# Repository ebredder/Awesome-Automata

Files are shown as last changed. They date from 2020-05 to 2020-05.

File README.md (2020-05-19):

# Awesome-Automata
Create large group automata for events and group projects to learn basic mechanisms.

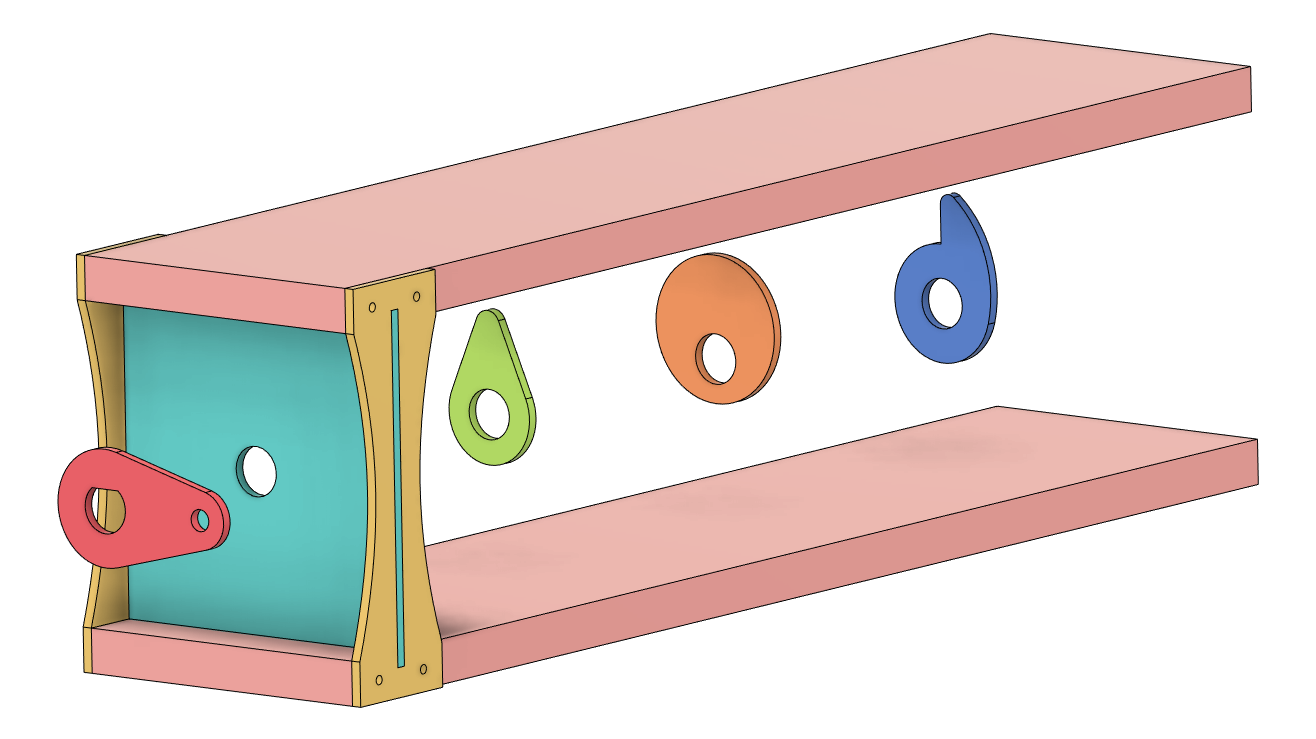
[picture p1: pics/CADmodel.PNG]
CAD


#### Materials Required:  
+ 1/2" ID Black Iron Pipe (length of your choosing)  
+ 6" (5.5" actual) Wide Board  
+ Wood Glue  
+ 5/8" Dowel Rods  
+ 1 1/4" #6 Screws  
+ 3/8" Bolt/Nut

#### Minimum Tools Required:  
+ Hacksaw  
+ Drill/Driver  
+ Screwdriver  
+ Metal File  
+ Sandpaper  
+ Crosscut Saw  
+ Circular Saw/Table Saw  

#### Optional Materials
+ Paint Supplies
+ Hot Glue/CA Glue
+ Foam Board, Craft Supplies, etc...
+ Paste Wax for lubrication

The sides can be made using a laser cutter, CNC Router, or even just printing the 1:1 templates and cutting with a bandsaw or jigsaw works too!

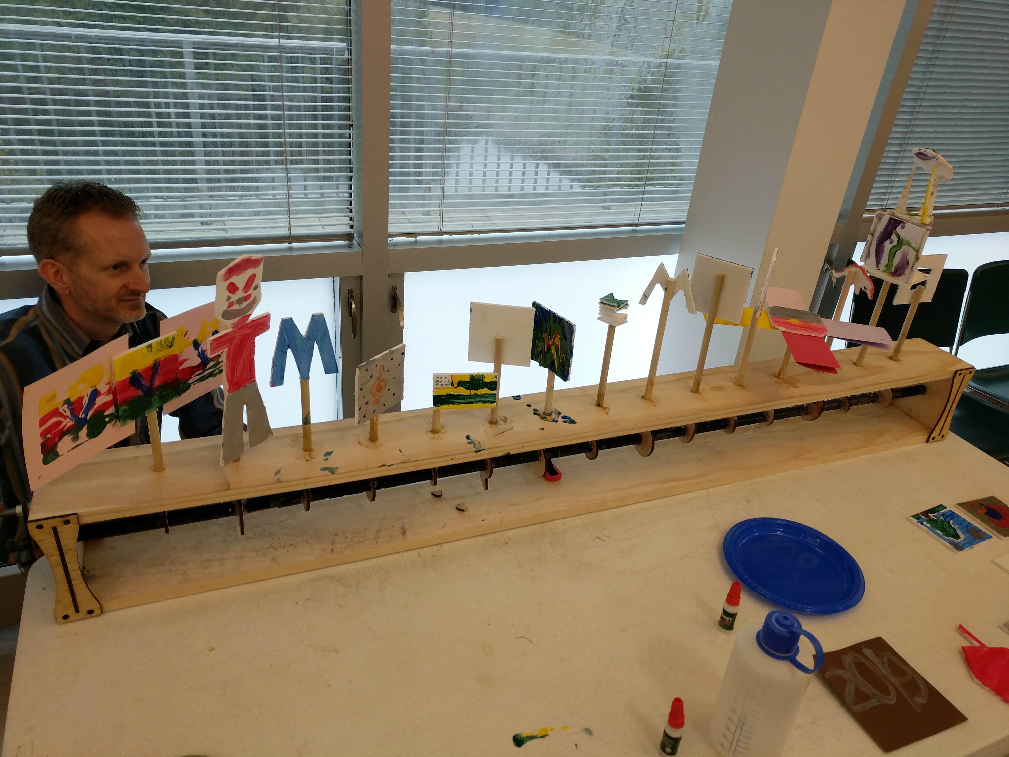
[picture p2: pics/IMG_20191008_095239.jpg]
project


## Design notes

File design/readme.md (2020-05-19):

All basic design files to get started are uploaded here. A Fusion 360 model of the construction of one side is located here (.f3d) with some 2D template exports of the pieces (.dxf) along with a complete project laser cut template (.svg).

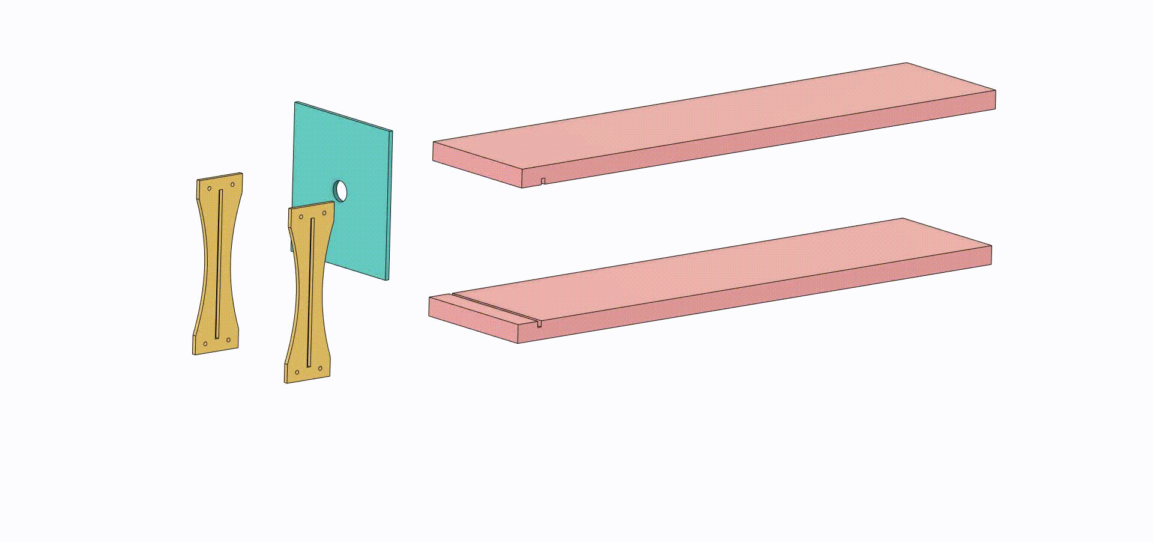
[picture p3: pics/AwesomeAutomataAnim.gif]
anim


#### Design for 5mm thick material - 

3 Cam profiles: Eccentric, Pear, Snail

4x Side Supports for frame  
2x Center Support for frame

1x Handle for crank mechanism

Center holes from cam used as followers on the cam shafts.

Laser Cut template also below to fit a 12x24" bed. Creates several cam profiles and all the required materials for one scalable mechanism.

**Note 1: Each of the boards will receive a 1/4" deep, 5mm (material thickness) wide dado that is 1" from each end of the board on the top and bottom. This makes 4 dados total.**

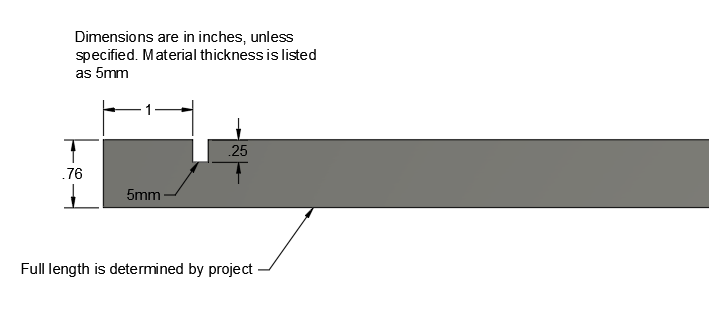
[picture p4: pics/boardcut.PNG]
board Dim
 

**Note 2: The iron pipe must be filed about .1" down to receive the crank in order to properly turn all the cams**

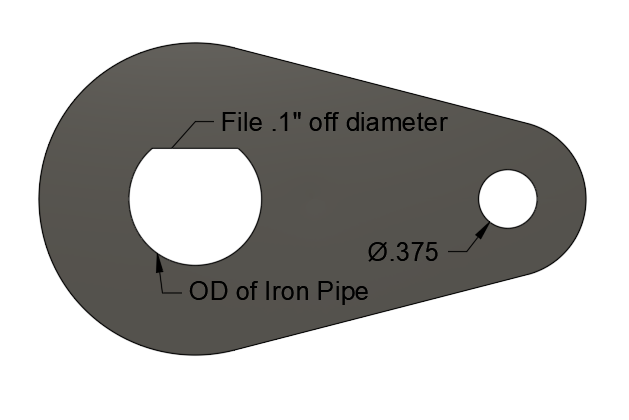
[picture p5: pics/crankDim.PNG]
crank


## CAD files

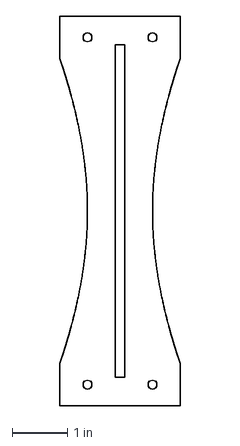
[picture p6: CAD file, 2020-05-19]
design/sideSupport.dxf
2.17 x 7.02 in

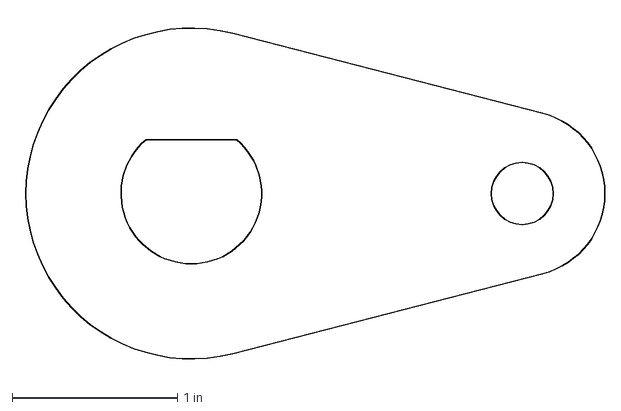
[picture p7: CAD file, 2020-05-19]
design/handle.dxf
3.56 x 2.15 in

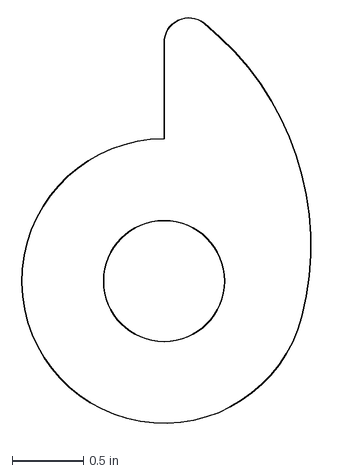
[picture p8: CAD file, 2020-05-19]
design/snailCam.dxf
2.21 x 2.93 in

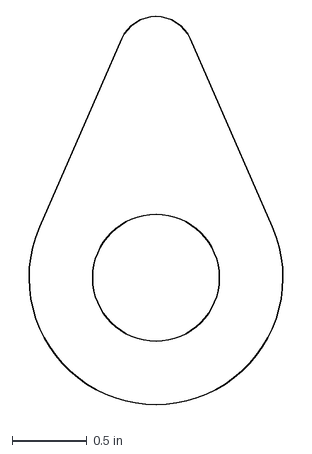
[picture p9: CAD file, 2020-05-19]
design/pearCam.dxf
1.87 x 2.66 in

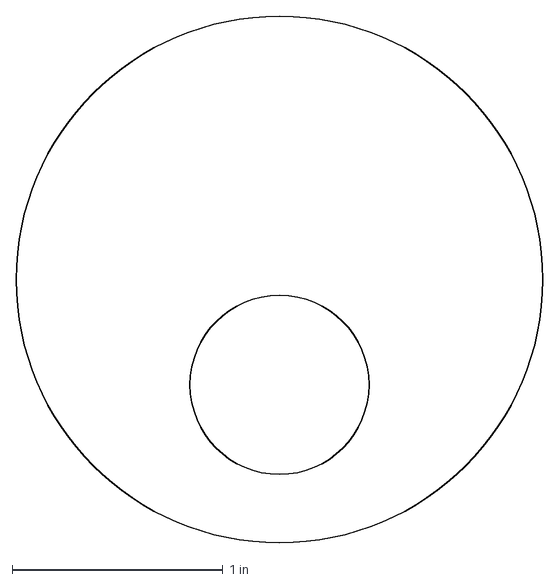
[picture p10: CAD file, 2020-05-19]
design/eccentricCam.dxf
2.50 x 2.50 in

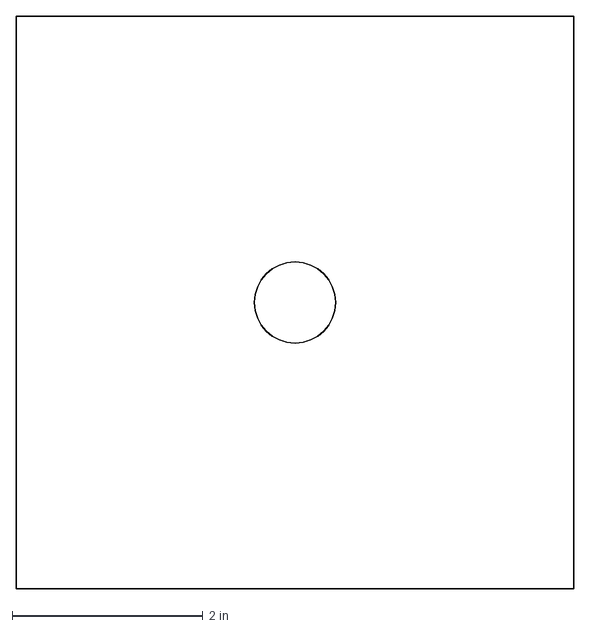
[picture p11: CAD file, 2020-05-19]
design/centerSupport.dxf
5.85 x 6.00 in

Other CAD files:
design/awesomeAutomataCAD.f3d
